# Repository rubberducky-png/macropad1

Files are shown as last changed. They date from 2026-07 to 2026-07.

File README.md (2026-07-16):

# rektek macropad
It has 9 keys (9 switches), a rotary encoder, and an OLED display. Each key is backlit with SK6812 MINI-E LEDs. It uses [QMK](https://qmk.fm/) firmware

## CAD Model:
Everything is connected by four M3x16mm screws and M3x5mx4mm heatset inserts. The case is printed in two parts, top and bottom.
<p align="center">
  

</p>
<p align="center">
  <strong>Made in onShape</strong>
</p>

## PCB:
<p align="center">
  Schematic
</p>
<p align="center">
  
</p>
<br>
<p align="center">
  PCB
</p>
<p align="center">
 
</p>
<p align="center">
  <strong>Made in KiCad</strong>
</p>

## Case:
<p align="center">
 
</p>
<p align="center">
  <strong>Made in onShape</strong>
</p>

## Firmware:
This Hackpad uses KMK.
#   Row 1: Rewind          Play/Pause      Fast Forward
#   Row 2: Netflix         Spotify         VS Code
#   Row 3: Left             Right           LED Mode Cycle

</p>

## Final result:
<p align="center">
 TBD
</p>
<p align="center">
    <b>HACKPAD DEMO WILL BE HERE</b>
  </a>
</p>
I really enjoyed creating my own hackpad, I learned how to create PCBs and schematics in KiCAD. There were a few mistakes in the model, but I was able to fix them pretty easily

## BOM:
Here is everything you need to create this Hackpad:
| Component | Amount |
| :--- | :---: |
| **Seeed XIAO RP2040** | 1x |
| **MX-Style switches** | 9x |
| **1N4148 Diodes** | 9x | 
| **EC11 Rotary encoder** | 1x |
| **0.91 inch OLED display** | 1x |
| **DSA keycaps** | 9x |
| **SK6812 MINI-E LED** | 12x |
| **M3x16mm screw** | 4x |
| **M3x5mx4mm heatset insert** | 4x |
| **Case** (2 printed parts) | 1x |
| **PCB** | 1x |

<hr>

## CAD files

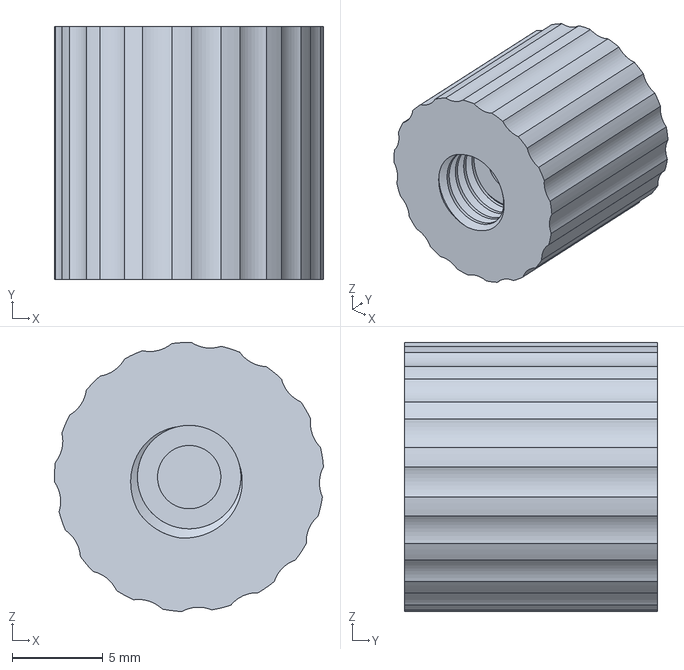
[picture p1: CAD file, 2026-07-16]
production/rotarycap.step
14.9 x 14.0 x 14.9 mm

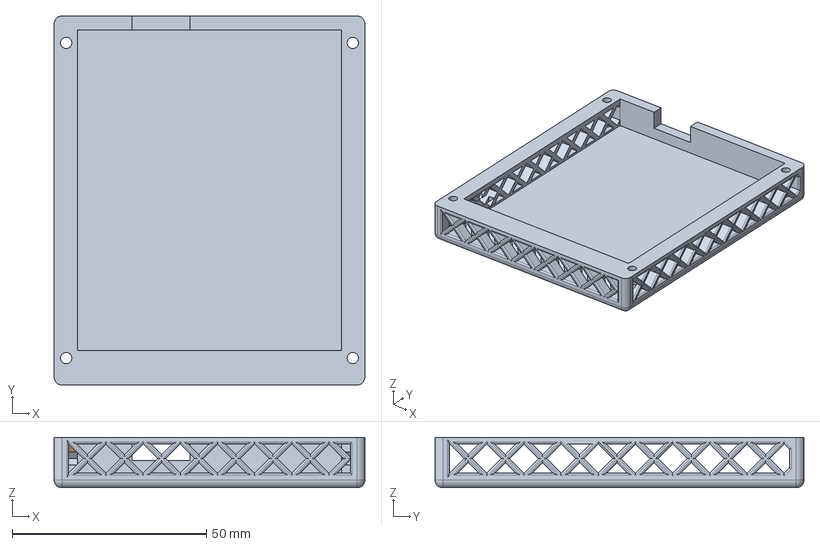
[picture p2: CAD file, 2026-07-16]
production/bottomcase.step
80.0 x 95.0 x 13.0 mm

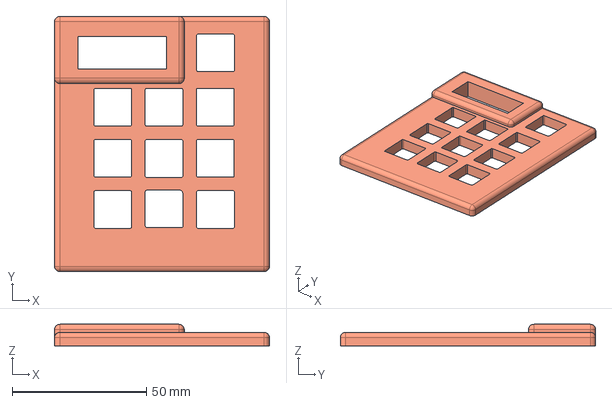
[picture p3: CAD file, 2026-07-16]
production/topcase.step
80.0 x 95.0 x 8.00 mm

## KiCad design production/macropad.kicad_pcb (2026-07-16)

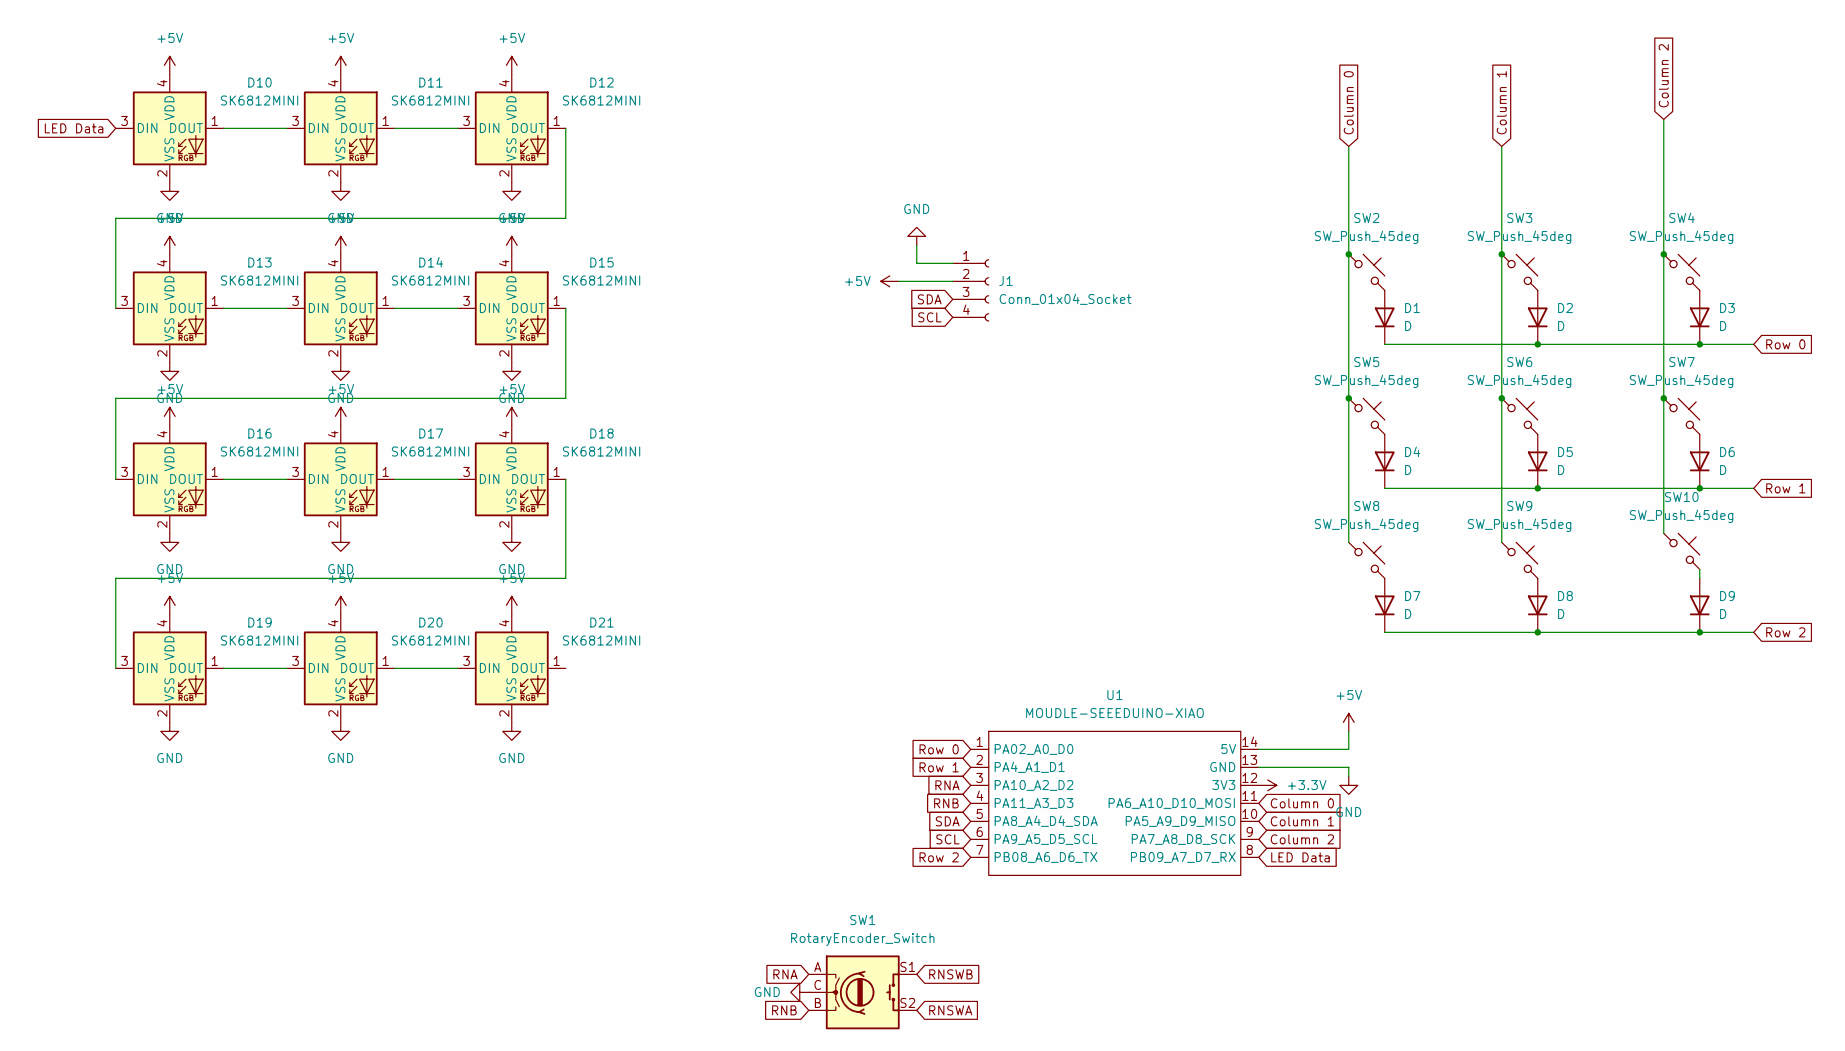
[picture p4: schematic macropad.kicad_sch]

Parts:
D1, D2, D3, D4, D5, D6, D7, D8, D9: D; D_DO-35_SOD27_P7.62mm_Horizontal
D10, D11, D12, D13, D14, D15, D16, D17, D18, D19, D20, D21: SK6812MINI; LED_SK6812MINI_PLCC4_3.5x3.5mm_P1.75mm
J1: Conn_01x04_Socket; SSD1306-0.91-OLED-4pin-128x32
SW1: RotaryEncoder_Switch; RotaryEncoder_Alps_EC11E-Switch_Vertical_H20mm
SW2, SW3, SW4, SW5, SW6, SW7, SW8, SW9, SW10: SW_Push_45deg; SW_Cherry_MX_1.00u_PCB
U1: MOUDLE-SEEEDUINO-XIAO; XIAO-Generic-Hybrid-14P-2.54-21X17.8MM

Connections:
+3.3V: U1.12 (3V3)
+5V: D10.4 (VDD), D11.4 (VDD), D12.4 (VDD), D13.4 (VDD), D14.4 (VDD), D15.4 (VDD), D16.4 (VDD), D17.4 (VDD), D18.4 (VDD), D19.4 (VDD), D20.4 (VDD), D21.4 (VDD), J1.2, U1.14 (5V)
Column 0: SW2.1, SW5.1, SW8.1, U1.11 (PA6_A10_D10_MOSI)
Column 1: SW3.1, SW6.1, SW9.1, U1.10 (PA5_A9_D9_MISO)
Column 2: SW4.1, SW7.1, SW10.1, U1.9 (PA7_A8_D8_SCK)
GND: D10.2 (VSS), D11.2 (VSS), D12.2 (VSS), D13.2 (VSS), D14.2 (VSS), D15.2 (VSS), D16.2 (VSS), D17.2 (VSS), D18.2 (VSS), D19.2 (VSS), D20.2 (VSS), D21.2 (VSS), J1.1, SW1.C, U1.13 (GND)
LED Data: D10.3 (DIN), U1.8 (PB09_A7_D7_RX)
unnamed: D1.2 (A), SW2.2
unnamed: D2.2 (A), SW3.2
unnamed: D3.2 (A), SW4.2
unnamed: D4.2 (A), SW5.2
unnamed: D5.2 (A), SW6.2
unnamed: D6.2 (A), SW7.2
unnamed: D7.2 (A), SW8.2
unnamed: D8.2 (A), SW9.2
unnamed: D9.2 (A), SW10.2
unnamed: D10.1 (DOUT), D11.3 (DIN)
unnamed: D11.1 (DOUT), D12.3 (DIN)
unnamed: D12.1 (DOUT), D13.3 (DIN)
unnamed: D13.1 (DOUT), D14.3 (DIN)
unnamed: D14.1 (DOUT), D15.3 (DIN)
unnamed: D15.1 (DOUT), D16.3 (DIN)
unnamed: D16.1 (DOUT), D17.3 (DIN)
unnamed: D17.1 (DOUT), D18.3 (DIN)
unnamed: D18.1 (DOUT), D19.3 (DIN)
unnamed: D19.1 (DOUT), D20.3 (DIN)
unnamed: D20.1 (DOUT), D21.3 (DIN)
RNA: SW1.A, U1.3 (PA10_A2_D2)
RNB: SW1.B, U1.4 (PA11_A3_D3)
RNSWA: SW1.S2
RNSWB: SW1.S1
Row 0: D1.1 (K), D2.1 (K), D3.1 (K), U1.1 (PA02_A0_D0)
Row 1: D4.1 (K), D5.1 (K), D6.1 (K), U1.2 (PA4_A1_D1)
Row 2: D7.1 (K), D8.1 (K), D9.1 (K), U1.7 (PB08_A6_D6_TX)
SCL: J1.4, U1.6 (PA9_A5_D5_SCL)
SDA: J1.3, U1.5 (PA8_A4_D4_SDA)

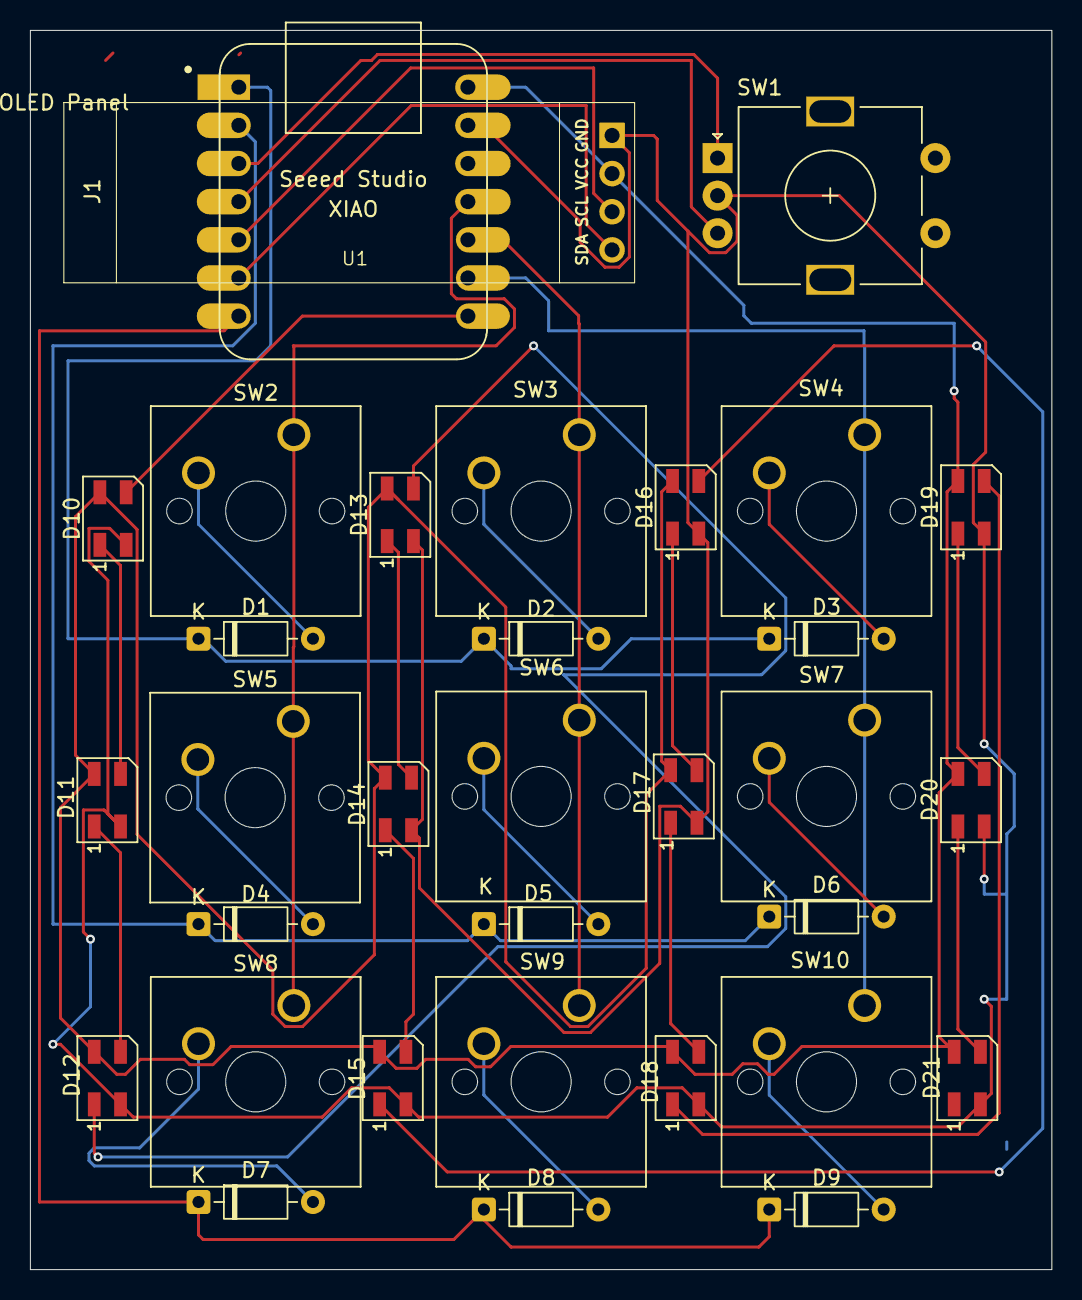
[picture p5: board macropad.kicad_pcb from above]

Board: 2 copper layers, 68.0 x 82.5 mm, 33 parts (0 on the bottom side), 33 nets.

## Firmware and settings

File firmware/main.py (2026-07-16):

import json
import usb_cdc

from kb import keyboard, encoder_handler, rgb, vol_label, rgb_label, song_label
from kmk.keys import KC
from kmk.modules import Module
from kmk.modules.macros import Macros
from kmk.extensions.RGB import AnimationModes

macros = Macros()
keyboard.modules.append(macros)

KC_NETFLIX = KC.MACRO(
    KC.LGUI, 150,
    'netflix', 300,
    KC.ENTER,
)

KC_SPOTIFY = KC.MACRO(
    KC.LGUI, 150,
    'spotify', 300,
    KC.ENTER,
)

KC_VSCODE = KC.MACRO(
    KC.LGUI, 150,
    'visual studio code', 400,
    KC.ENTER,
)


LED_MODES = [
    AnimationModes.BREATHING,          
    AnimationModes.RAINBOW,             
    AnimationModes.SWIRL,               
    AnimationModes.BREATHING_RAINBOW,  
    None,                              
]
LED_MODE_NAMES = ["Solid", "Rainbow", "Wave", "Grid Fade", "Off"]
_led_mode_index = 0


def cycle_led_modes(key, keyboard, *args):
    global _led_mode_index
    _led_mode_index = (_led_mode_index + 1) % len(LED_MODES)
    mode = LED_MODES[_led_mode_index]

    if mode is None:
        rgb.enable = False
    else:
        rgb.enable = True
        rgb.animation_mode = mode
        if mode == AnimationModes.BREATHING:
            rgb.hue = 160  

    rgb_label.text = "RGB: " + LED_MODE_NAMES[_led_mode_index]

    return keyboard


KC_LED_CYCLE = KC.new_key(on_press=cycle_led_modes)


SONG_LINE_MAX_CHARS = 21 


class PCBridge(Module):
    def __init__(self):
        self._serial = usb_cdc.data
        self._buf = ""

    def during_bootup(self, keyboard):
        return

    def before_matrix_scan(self, keyboard):
        if self._serial is None or not self._serial.in_waiting:
            return keyboard

        try:
            chunk = self._serial.read(self._serial.in_waiting).decode("utf-8")
        except Exception:
            return keyboard

        self._buf += chunk
        while "\n" in self._buf:
            line, self._buf = self._buf.split("\n", 1)
            self._handle_line(line.strip())

        return keyboard

    def _handle_line(self, line):
        if not line:
            return
        try:
            data = json.loads(line)
        except ValueError:
            return

        vol = data.get("vol")
        if vol is not None:
            vol_label.text = "Vol: {}%".format(vol)

        if data.get("playing") and data.get("song"):
            artist = data.get("artist")
            text = "{} - {}".format(data["song"], artist) if artist else data["song"]
            song_label.text = text[:SONG_LINE_MAX_CHARS]
        else:
            song_label.text = "No media playing"

    def after_matrix_scan(self, keyboard):
        return keyboard

    def process_key(self, keyboard, key_event):
        return key_event

    def before_hid_send(self, keyboard):
        return keyboard

    def after_hid_send(self, keyboard):
        return keyboard

    def on_powersave_enable(self, keyboard):
        return keyboard

    def on_powersave_disable(self, keyboard):
        return keyboard


keyboard.modules.append(PCBridge())

keyboard.keymap = [
    [
        KC.MRWD,     KC.MPLY,     KC.MFFD,
        KC_NETFLIX,  KC_SPOTIFY,  KC_VSCODE,
        KC.LEFT,     KC.RIGHT,    KC_LED_CYCLE,
    ]
]


encoder_handler.map = [
    ((KC.VOLD, KC.VOLU),),
]

if __name__ == '__main__':
    keyboard.go()

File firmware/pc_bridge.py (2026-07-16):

"""
Companion script for the SplashPad macropad's OLED.

Reads your system volume and whatever Windows says is "now playing"
(works with Spotify desktop, browser tabs, or anything else using the
Windows media session -- it's not Spotify-specific, it's whatever has
focus of the system media controls) and streams both to the XIAO
RP2040 over its USB data serial port, about once a second.

Setup:
    pip install pyserial pycaw comtypes winsdk

Usage:
    python pc_bridge.py            # auto-detects the board's COM port
    python pc_bridge.py COM7       # or force a specific port

Requires boot.py (enabling usb_cdc data) to already be on the board,
and the board to have been reset/replugged after copying it over.
"""

import asyncio
import json
import sys

import serial
import serial.tools.list_ports

from ctypes import cast, POINTER
from comtypes import CLSCTX_ALL
from pycaw.pycaw import AudioUtilities, IAudioEndpointVolume

from winsdk.windows.media.control import (
    GlobalSystemMediaTransportControlsSessionManager as MediaManager,
    GlobalSystemMediaTransportControlsSessionPlaybackStatus as PlaybackStatus,
)

POLL_SECONDS = 1.5


def find_port():
    if len(sys.argv) > 1:
        return sys.argv[1]
    for p in serial.tools.list_ports.comports():
        desc = p.description or ""
        if "CircuitPython" in desc or "XIAO" in desc:
            return p.device
    raise RuntimeError(
        "Couldn't auto-find the board's serial port. Check Device Manager "
        "for its COM port and run: python pc_bridge.py COMx"
    )


def get_volume():
    devices = AudioUtilities.GetSpeakers()
    interface = devices.Activate(IAudioEndpointVolume._iid_, CLSCTX_ALL, None)
    volume = cast(interface, POINTER(IAudioEndpointVolume))
    return round(volume.GetMasterVolumeLevelScalar() * 100)


async def get_media_info():
    manager = await MediaManager.request_async()
    session = manager.get_current_session()
    if session is None:
        return None, None, False

    info = await session.try_get_media_properties_async()
    playback_info = session.get_playback_info()
    is_playing = playback_info.playback_status == PlaybackStatus.PLAYING
    return info.title, info.artist, is_playing


async def main():
    port_name = find_port()
    print("Connecting to {}...".format(port_name))
    ser = serial.Serial(port_name, baudrate=115200, timeout=1)

    while True:
        try:
            vol = get_volume()
        except Exception as e:
            print("Volume read failed:", e)
            vol = None

        try:
            title, artist, playing = await get_media_info()
        except Exception as e:
            print("Media read failed:", e)
            title, artist, playing = None, None, False

        payload = {
            "vol": vol,
            "song": title,
            "artist": artist,
            "playing": playing,
        }

        try:
            ser.write((json.dumps(payload) + "\n").encode("utf-8"))
        except Exception as e:
            print("Serial write failed:", e)

        await asyncio.sleep(POLL_SECONDS)


if __name__ == "__main__":
    asyncio.run(main())

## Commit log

2026-07-16 Replace old images with new CAD model image
    Updated images in README.md to reflect new CAD model.
2026-07-16 Rename Assembly 1 Copy 1.step to CAD/completeAssembly
2026-07-16 Add bottomcase file to CAD directory
2026-07-16 Add topcase file to CAD directory
2026-07-16 Rename Assembly 1 Copy 1.step to CAD/Entirety
2026-07-16 Update and rename CAD/Entirety to k
2026-07-16 Add rotarycap.step file to production directory
    [rotarycap.step]
